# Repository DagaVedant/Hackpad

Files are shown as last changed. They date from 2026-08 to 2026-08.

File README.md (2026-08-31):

# minipad

a 3x3 macropad for shortcuts, built for [hackpad](https://hackpad.hackclub.com).
9 keys, a rotary encoder, per key rgb, and a 0.91" oled that shows a clock and a
spinning globe.

## the pad

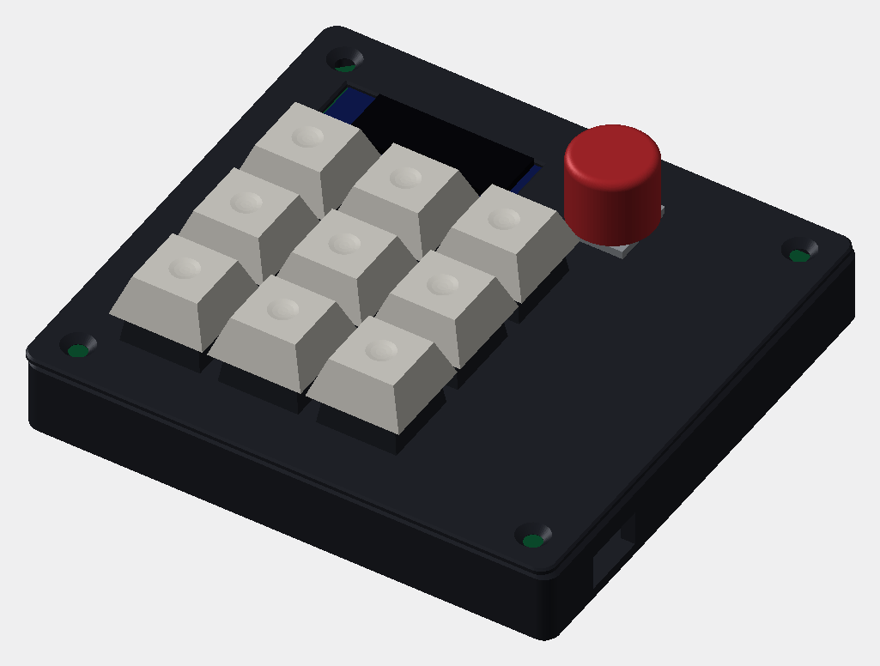
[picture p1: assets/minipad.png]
minipad


rendered from the actual case and board files in this repo, not a mockup. photo
of the real thing goes here once it's printed and soldered.

## schematic

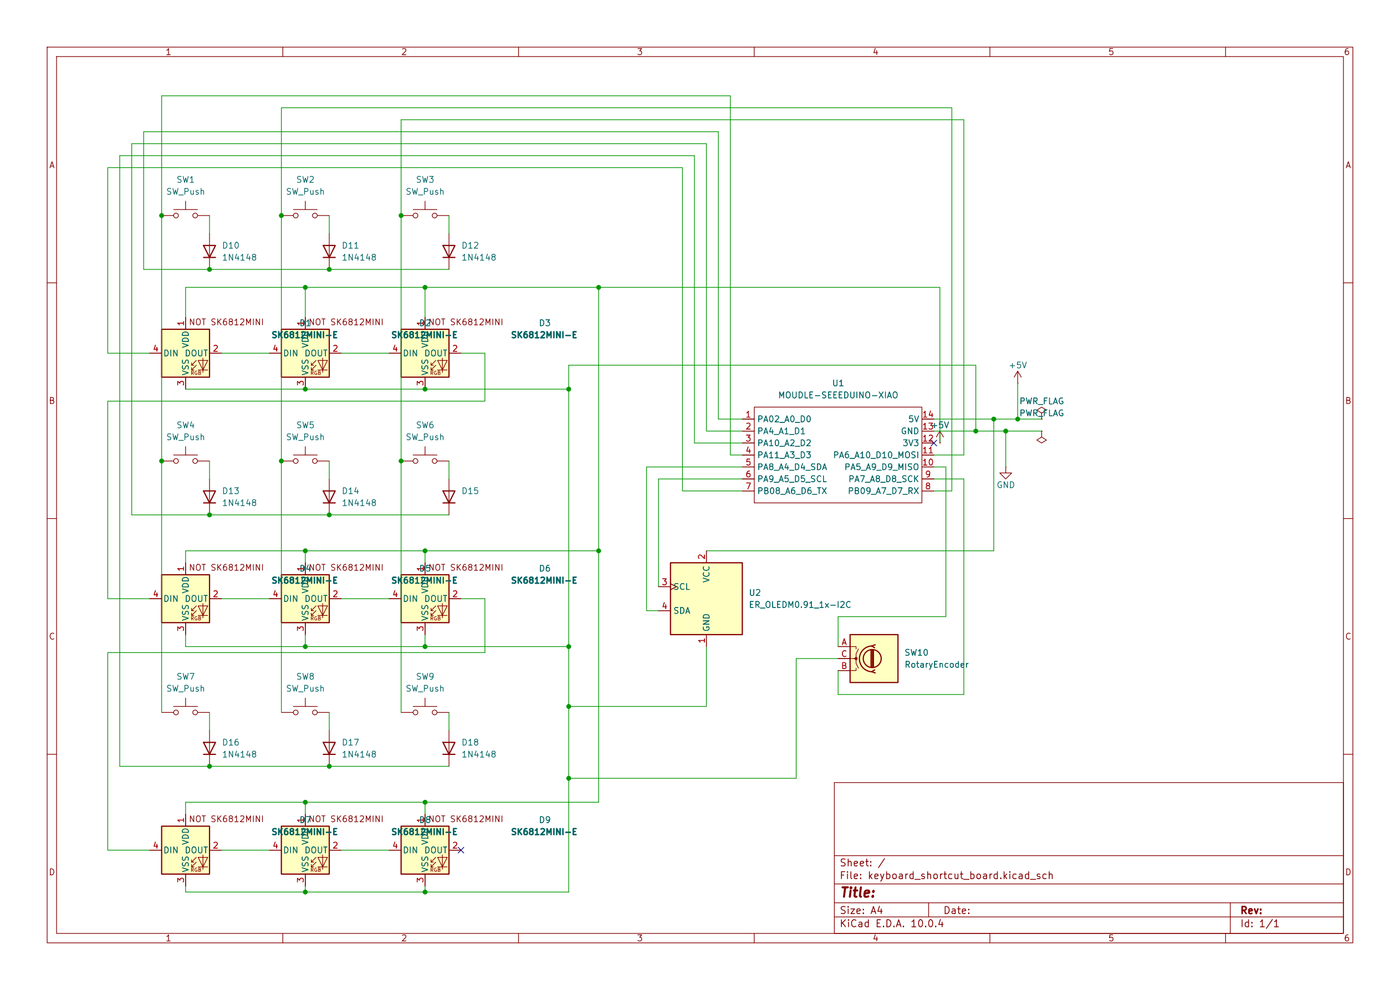
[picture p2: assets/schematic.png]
schematic


## pcb

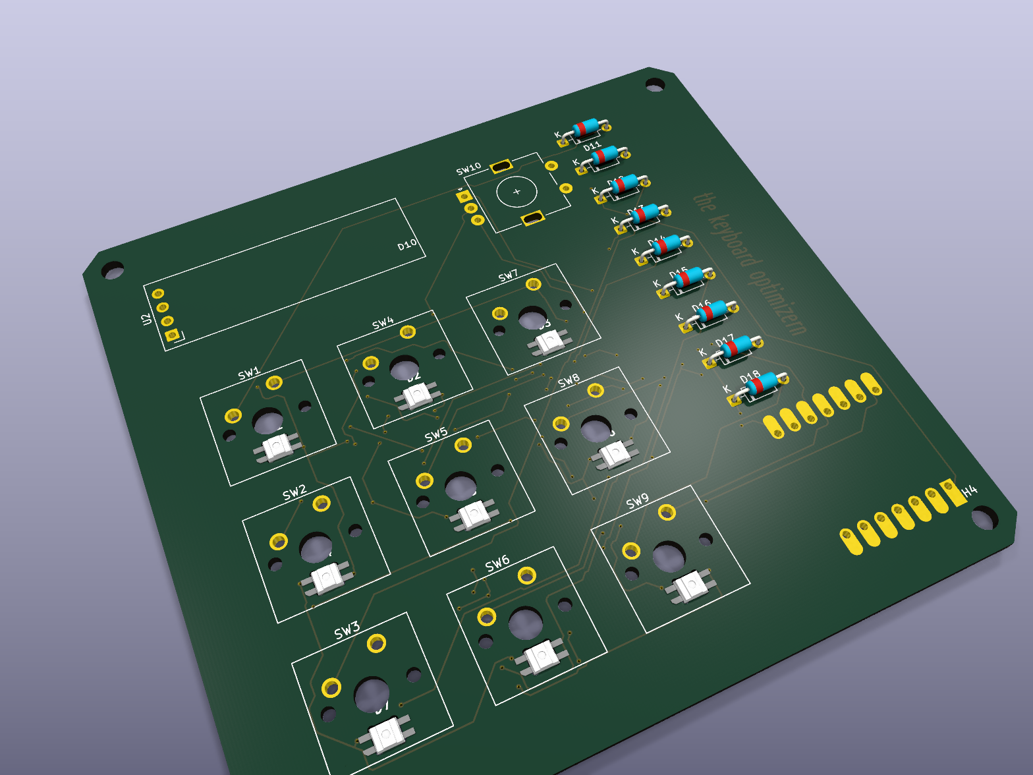
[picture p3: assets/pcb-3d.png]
pcb


96.38 x 90.90mm, 2 layers. chamfered corners, and 4x m3 mounting holes on an
88.226 x 82.748mm rectangle for a sandwich case.

the 9 sk6812mini-e leds are reverse mounted. they sit in milled slots in the
board and shine up through the switches, so the lighting is per key rather than
underglow.

## case

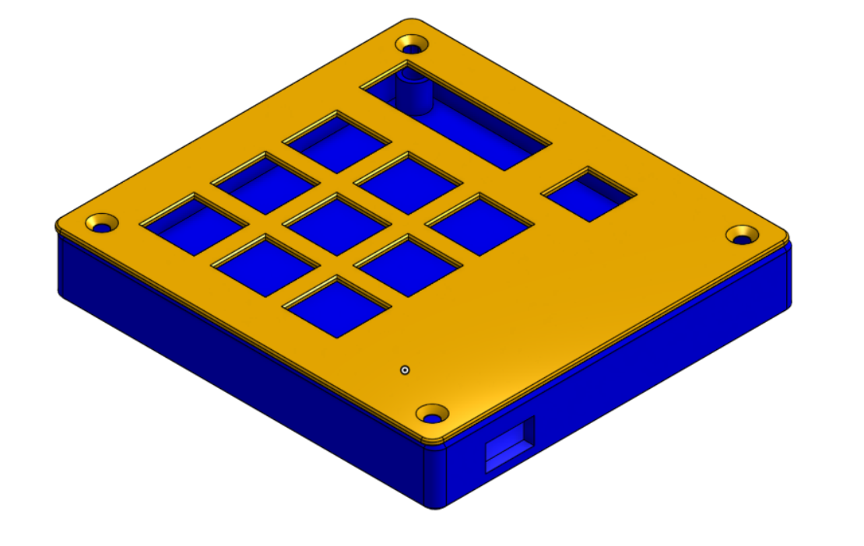
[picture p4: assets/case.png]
case


[open the assembly in onshape](https://cad.onshape.com/documents/58a01ca66c97d1b4010a7a00/w/fc5b38729478e50a03cca7d8/e/0de70a1a8ca9505f551d6dfe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)

a sandwich: 1.5mm switch plate on top, the pcb in the middle, tray bottom
underneath. 102.38 x 96.90mm overall, 16.6mm tall closed.

the pcb rests on four bosses at 10mm, which leaves a 7.5mm cavity under the
board for the reverse mounted leds and the xiao. m3 heatset inserts drop into
the bosses from above, and four m3 screws through the plate into those inserts
hold the stack together. the only overhang is the usb-c slot in the side wall,
which is a 7mm bridge.

`production/Top.STEP` and `production/Bottom.STEP` are the two printable parts.
`cad/Assembly.STEP` is the whole thing put together, with the pcb in it.

## oled

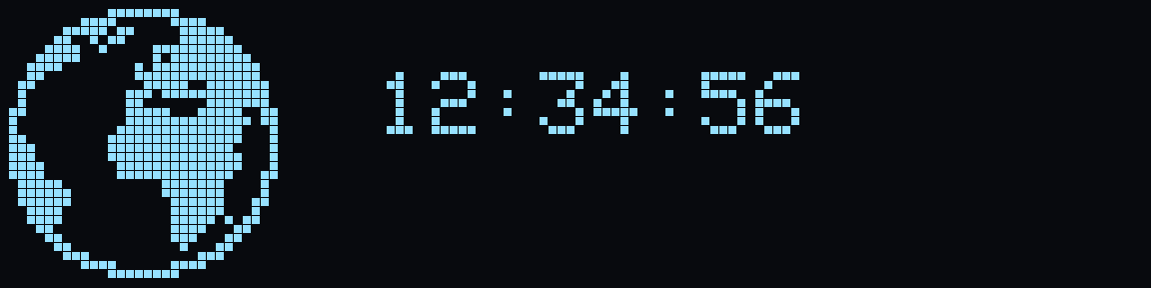
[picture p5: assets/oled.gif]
oled


the globe is generated from real natural earth coastline data. 24 frames, made
by projecting the land polygons onto a tilted sphere, so those are actual
continents at 32x32 pixels.

## bom

| qty | part | refs | in the hackpad kit? |
|---|---|---|---|
| 1 | seeed xiao rp2040 | U1 | yes (1 supplied) |
| 9 | mx style switch | SW1-SW9 | yes (16 supplied) |
| 9 | 1n4148 diode, do-35 | D10-D18 | yes (20 supplied) |
| 9 | sk6812mini-e rgb led | D1-D9 | yes (20 supplied) |
| 1 | ec11 rotary encoder, 20mm d-shaft | SW10 | yes (2 supplied) |
| 1 | 0.91" 128x32 i2c oled | U2 | yes (1 supplied) |
| 9 | dsa blank keycap | - | yes (16 supplied) |
| 4 | m3x16 screw | H1-H4 | yes (6 supplied) |
| 4 | m3x5x4 heatset insert | H1-H4 | yes (6 supplied) |
| 1 | knob for the encoder | - | **no, print it or source it yourself** |

everything except the encoder knob comes from the standard kit.

## keymap

| | | |
|---|---|---|
| open spotify | open chrome | open vs code |
| f11 | screenshot | calculator |
| copy | paste | undo |

the encoder does volume.

the three app launchers use windows taskbar shortcuts (`win`+`1`/`2`/`3`), so
**pin spotify, chrome and vs code to the first three taskbar slots** and the top
row works with no extra software.

## clock

there's no rtc on the board and usb hid can't send the time, so the clock
free runs from a timer and you set it by hand:

- hold the two **top corner keys** together to toggle set mode
- **encoder** adjusts minutes
- **top left / top right** keys adjust hours
- **top middle** exits

it resets to 00:00:00 whenever you unplug it, and drifts a few seconds a day.

## pins

| xiao pin | rp2040 | function |
|---|---|---|
| d0, d1, d2 | gp26, gp27, gp28 | matrix columns |
| d3, d7, d10 | gp29, gp1, gp3 | matrix rows |
| d4, d5 | gp6, gp7 | oled i2c (sda, scl) |
| d6 | gp0 | sk6812 data |
| d8, d9 | gp2, gp4 | encoder b, a |

3x3 matrix, `row2col`. all 11 gpio are used, which is why the encoder's push
switch isn't wired.

## firmware

qmk. `production/firmware.uf2` is prebuilt, so to flash it just double tap reset
on the xiao and drag the file onto the drive that appears.

to build it yourself, drop `firmware/` into
`qmk_firmware/keyboards/minipad/` and run:

```
qmk compile -kb minipad -km default
```

## layout

```
pcb/         kicad source and the board step
firmware/    qmk source
cad/         assembled case model
production/  everything you need to build one: gerbers, the two
             printable case parts, and the prebuilt uf2
assets/      images for this readme
```

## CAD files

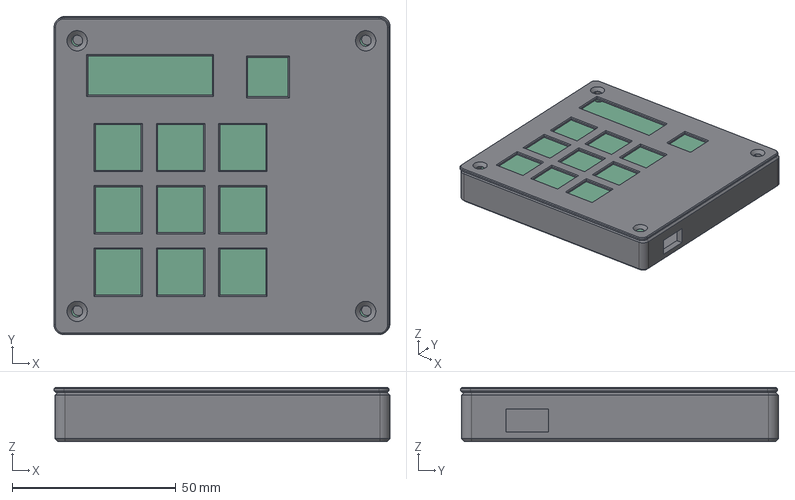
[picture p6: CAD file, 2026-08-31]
cad/Assembly.STEP
102.7 x 97.3 x 16.6 mm
case_bottom
pcb
switch_plate

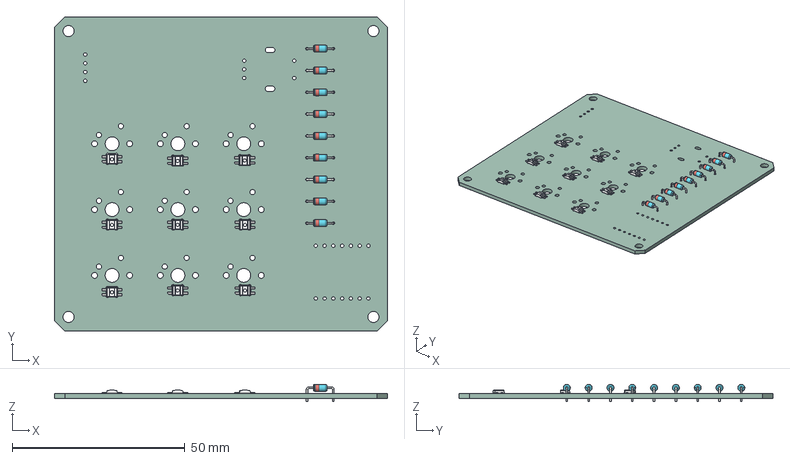
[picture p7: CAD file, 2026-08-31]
pcb/minipad.step
96.4 x 90.9 x 5.01 mm
Pin1 x 9
Pin2 x 9
Pin3 x 9
Pin4 x 9
D_DO-35_SOD27_P7.62mm_Horizontal x 9
minipad_PCB

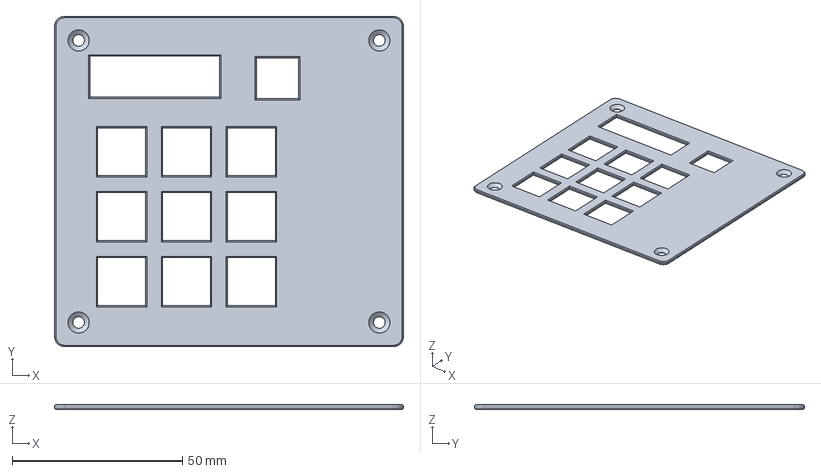
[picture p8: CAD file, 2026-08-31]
production/Top.STEP
102.4 x 96.9 x 1.50 mm

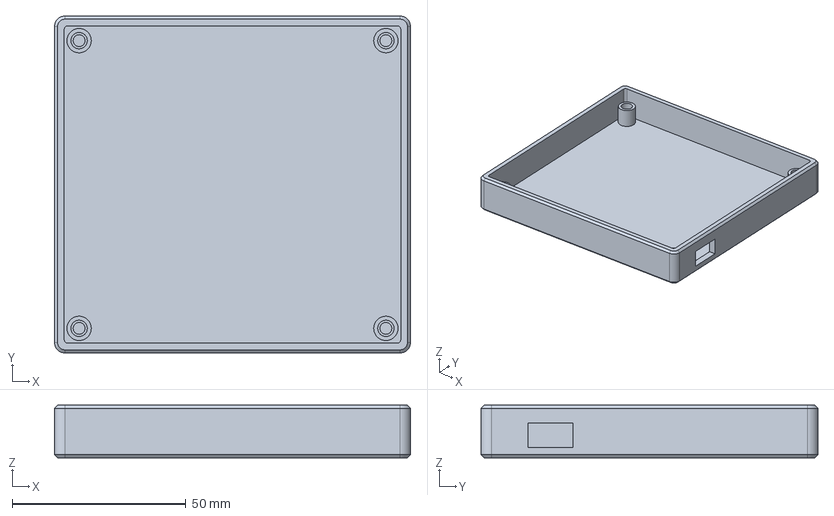
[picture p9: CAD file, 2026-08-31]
production/Bottom.STEP
102.4 x 96.9 x 15.1 mm

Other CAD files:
pcb/keyboard_shortcut_board.step

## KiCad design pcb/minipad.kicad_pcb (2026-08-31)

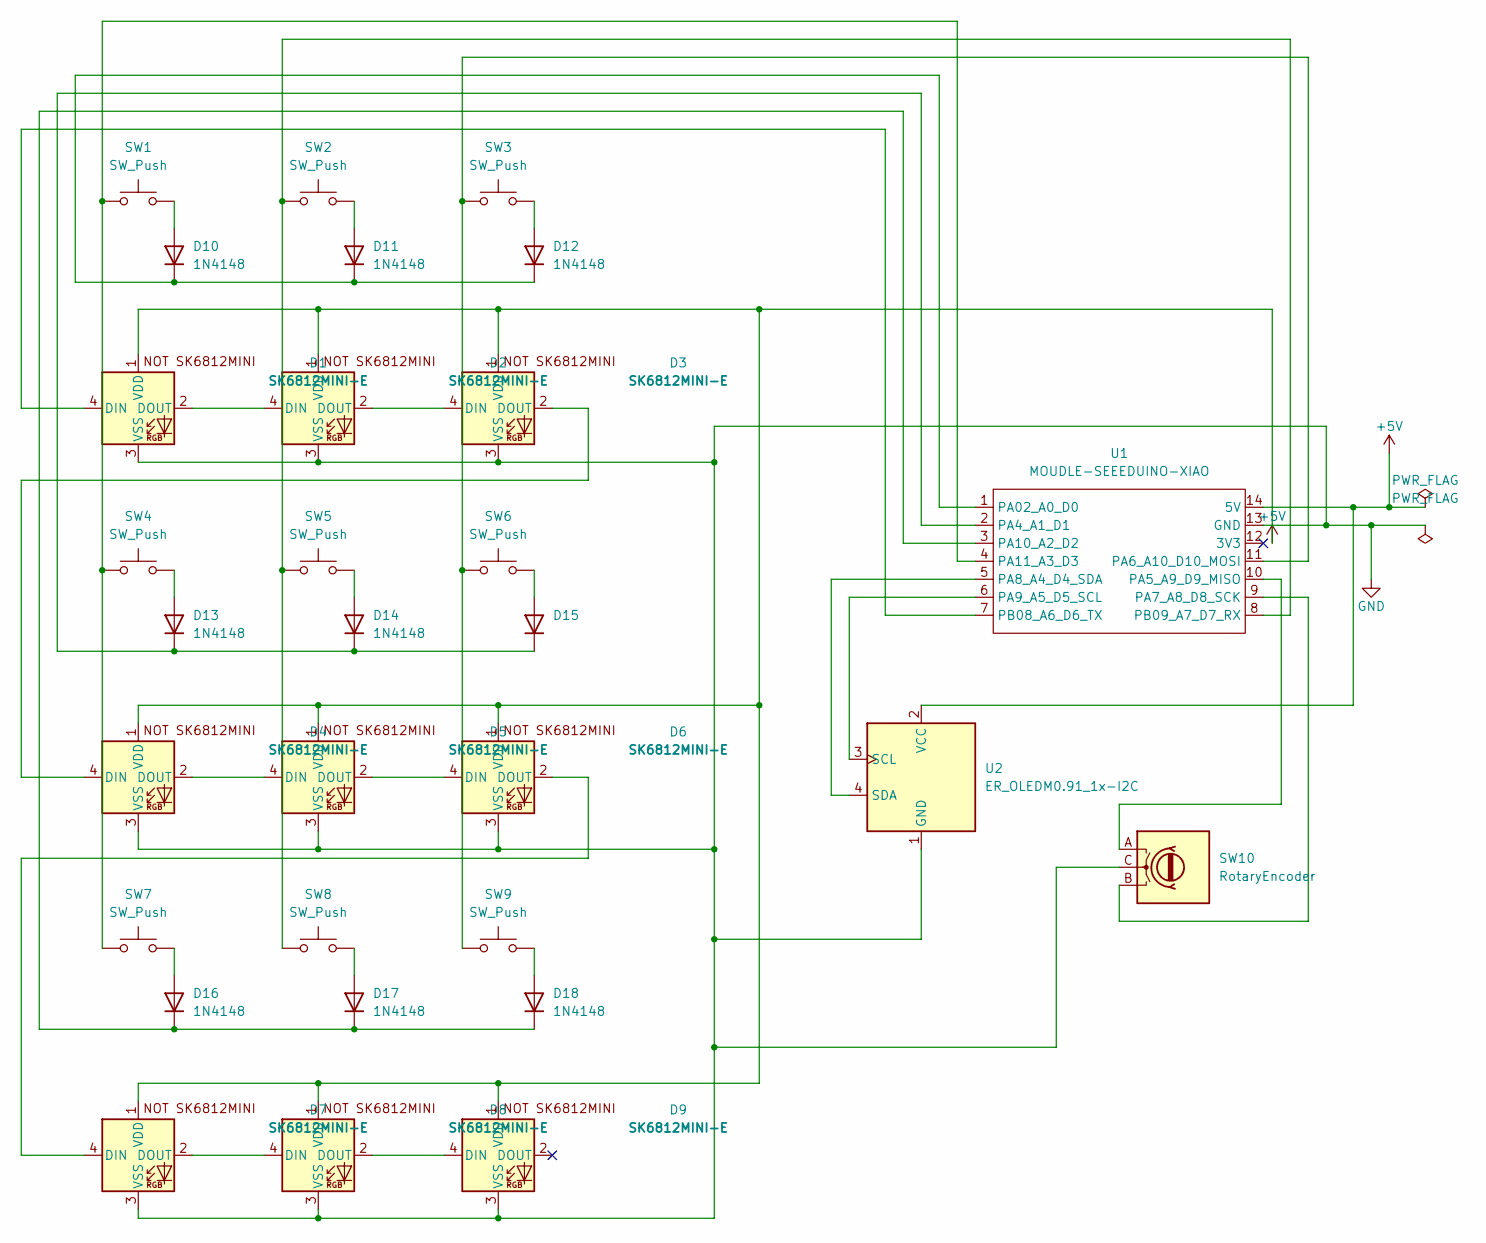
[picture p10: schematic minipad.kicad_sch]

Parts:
D1, D2, D3, D4, D5, D6, D7, D8, D9: SK6812MINI-E; SK6812MINI-E_fixed
D10, D11, D12, D13, D14, D15, D16, D17, D18: 1N4148; D_DO-35_SOD27_P7.62mm_Horizontal
SW1, SW2, SW3, SW4, SW5, SW6, SW7, SW8, SW9: SW_Push; SW_Cherry_MX_1.00u_PCB
SW10: RotaryEncoder; RotaryEncoder_Alps_EC11E-Switch_Vertical_H20mm
U1: MOUDLE-SEEEDUINO-XIAO; XIAO-Generic-Hybrid-14P-2.54-21X17.8MM
U2: ER_OLEDM0.91_1x-I2C

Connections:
+5V: D1.1 (VDD), D2.1 (VDD), D3.1 (VDD), D4.1 (VDD), D5.1 (VDD), D6.1 (VDD), D7.1 (VDD), D8.1 (VDD), D9.1 (VDD), U1.14 (5V), U2.2 (VCC)
GND: D1.3 (VSS), D2.3 (VSS), D3.3 (VSS), D4.3 (VSS), D5.3 (VSS), D6.3 (VSS), D7.3 (VSS), D8.3 (VSS), D9.3 (VSS), SW10.C, U1.13 (GND), U2.1 (GND)
unnamed: D1.4 (DIN), U1.7 (PB08_A6_D6_TX)
unnamed: D1.2 (DOUT), D2.4 (DIN)
unnamed: D2.2 (DOUT), D3.4 (DIN)
unnamed: D3.2 (DOUT), D4.4 (DIN)
unnamed: D4.2 (DOUT), D5.4 (DIN)
unnamed: D5.2 (DOUT), D6.4 (DIN)
unnamed: D6.2 (DOUT), D7.4 (DIN)
unnamed: D7.2 (DOUT), D8.4 (DIN)
unnamed: D8.2 (DOUT), D9.4 (DIN)
unnamed: D10.2 (A), SW1.2
unnamed: D10.1 (K), D11.1 (K), D12.1 (K), U1.1 (PA02_A0_D0)
unnamed: D11.2 (A), SW2.2
unnamed: D12.2 (A), SW3.2
unnamed: D13.2 (A), SW4.2
unnamed: D13.1 (K), D14.1 (K), D15.1 (K), U1.2 (PA4_A1_D1)
unnamed: D14.2 (A), SW5.2
unnamed: D15.2 (A), SW6.2
unnamed: D16.2 (A), SW7.2
unnamed: D16.1 (K), D17.1 (K), D18.1 (K), U1.3 (PA10_A2_D2)
unnamed: D17.2 (A), SW8.2
unnamed: D18.2 (A), SW9.2
unnamed: SW10.A, U1.10 (PA5_A9_D9_MISO)
unnamed: SW3.1, SW6.1, SW9.1, U1.11 (PA6_A10_D10_MOSI)
unnamed: SW10.B, U1.9 (PA7_A8_D8_SCK)
unnamed: U1.5 (PA8_A4_D4_SDA), U2.4 (SDA)
unnamed: U1.6 (PA9_A5_D5_SCL), U2.3 (SCL)
unnamed: SW1.1, SW4.1, SW7.1, U1.4 (PA11_A3_D3)
unnamed: SW2.1, SW5.1, SW8.1, U1.8 (PB09_A7_D7_RX)

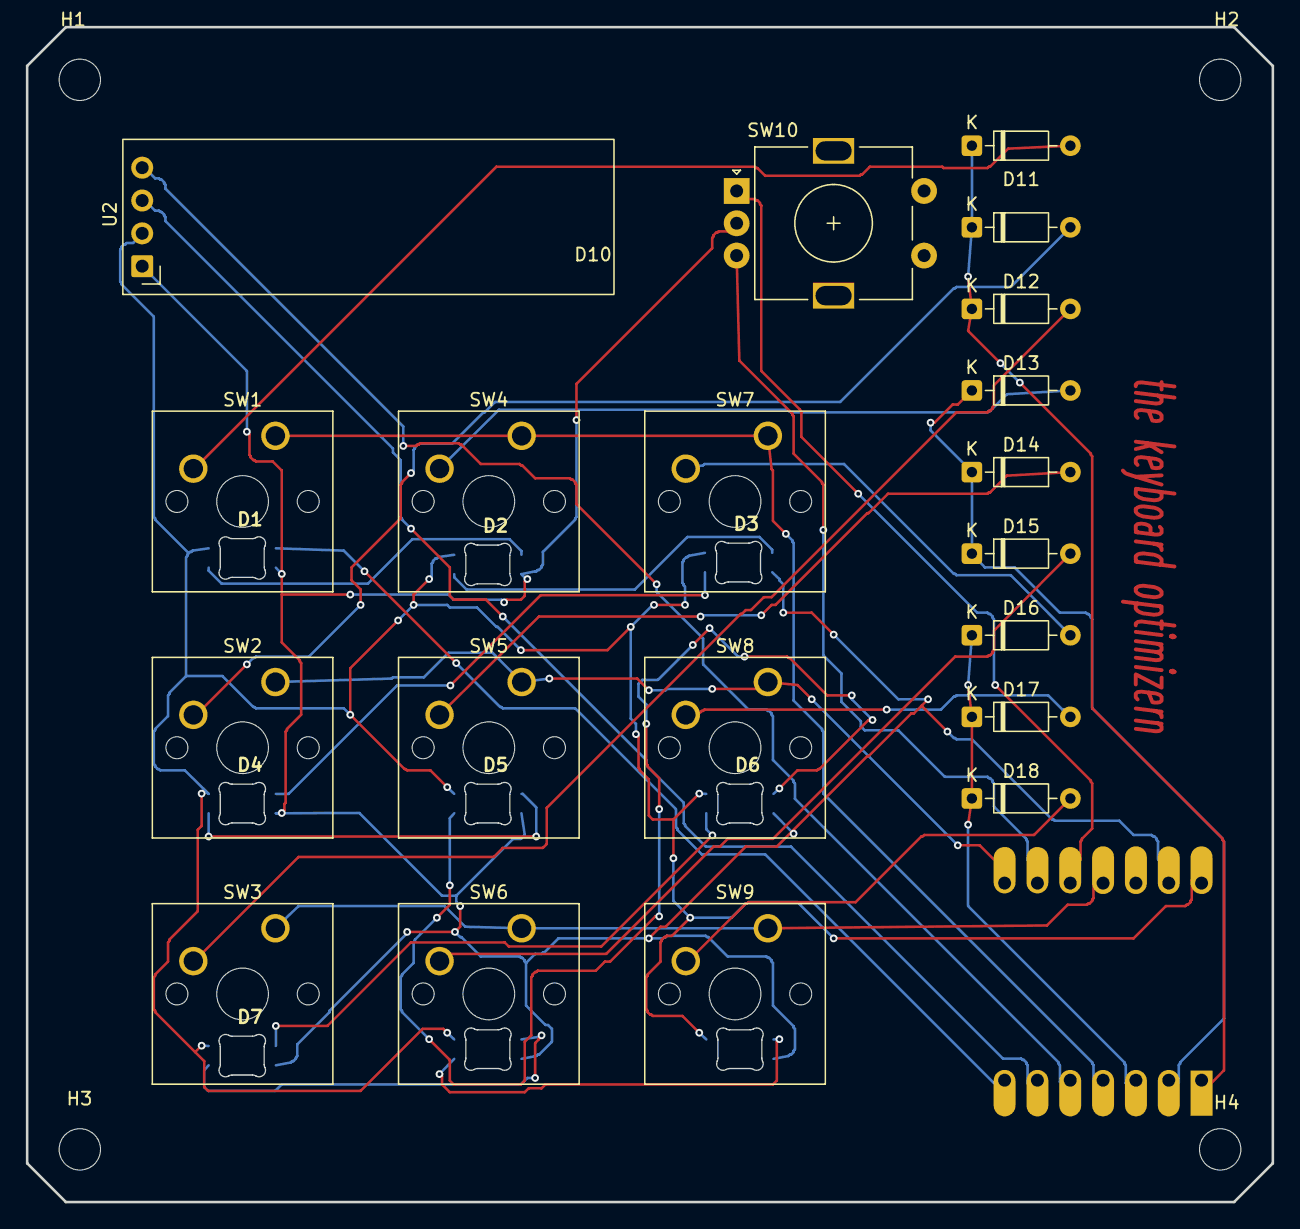
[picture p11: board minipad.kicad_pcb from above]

Board: 2 copper layers, 96.4 x 90.9 mm, 34 parts (1 on the bottom side), 30 nets.

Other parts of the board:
H1, H2, H3, H4: MountingHole_3.2mm_M3

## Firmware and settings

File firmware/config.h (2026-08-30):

#define ENCODER_A_PINS { GP4 }
#define ENCODER_B_PINS { GP2 }

#define WS2812_DI_PIN GP0
#define RGBLIGHT_LED_COUNT 9
#define RGBLIGHT_LIMIT_VAL 120

#define I2C_DRIVER I2CD1
#define I2C1_SDA_PIN GP6
#define I2C1_SCL_PIN GP7

#define OLED_TIMEOUT 0

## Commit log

2026-08-30 just build the schematic and pcb
    [keyboard_shortcut_board.kicad_pcb, keyboard_shortcut_board.kicad_sch]
2026-08-30 fix schematic power rails
    [keyboard_shortcut_board.kicad_pcb, keyboard_shortcut_board.kicad_sch]
2026-08-30 move XIAO 5mm right so USB-C clears the case wall
    Receptacle sat 7.64mm inboard of the right board edge after the mounting
    margin was added, too deep for a USB-C plug overmold to reach. Now 2.64mm.
    Re-routed all 13 nets on the XIAO. Also repointed the SK6812 footprints at
    the 3D model that actually ships with KiCad. DRC unchanged: 0 unconnected,
    44 LED slot-clearance errors inherent to the supplied footprint.
    [keyboard_shortcut_board.kicad_pcb]
2026-08-30 square up the M3 mounting holes and add the board STEP
    Holes were off a symmetric pattern by up to 0.7mm, so the case could not use
    a rectangular pattern. Now a true 88.226 x 82.748 rectangle, 4.076mm inset on
    all four edges.
    That inset centres the bottom-right hole in the 8.15mm band between the XIAO
    and the board edge, raising its clearance from 3.55 to 4.08mm so the heatset
    boss can be 8.15mm OD instead of 7.1mm.
    DRC unchanged: 0 unconnected, 44 LED slot-clearance errors from the supplied
    SK6812 footprint. Gerbers and STEP regenerated and verified against the board.
    [keyboard_shortcut_board.kicad_pcb, keyboard_shortcut_board.step]
2026-08-30 chamfer the board corners
    3mm chamfers on all four corners. Capped at 3mm by the M3 holes: they sit
    4.076mm in from each edge, so a bigger cut would leave under 2mm of board
    around the screw. The reference designs get away with large chamfers because
    they have no corner mounting holes.
    Bounding box unchanged at 96.38 x 90.90mm, no copper in the removed corners,
    DRC unchanged. Gerbers and STEP regenerated.
    [keyboard_shortcut_board.kicad_pcb, keyboard_shortcut_board.step]
2026-08-30 add compiled firmware.uf2
    Built with QMK 1.2.0 CLI, GNU Make 4.4.1 and Arm GNU Toolchain 12.2.
    text 33376 bytes, 131 UF2 blocks from 0x10000000, RP2040 family ID.
    Verified the keymap symbol and the encoder, OLED, RGB and I2C code are
    all linked in.
2026-08-30 OLED clock with spinning globe
    12-frame wireframe globe, 32x32, 1536 bytes of bitmap, rendered as a tilted
    sphere so the parallels project as ellipses and the rotation reads.
    No RTC exists in this QMK version and USB HID cannot deliver the time, so the
    clock free-runs from timer_read32 with an offset set by hand. Hold the two top
    corner keys to toggle a set layer, then the encoder adjusts minutes and the
    top-left and top-right keys adjust hours. All nine base functions survive.
    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
2026-08-30 replace the wireframe globe with a rendered Earth
    Frames are now rasterised from Natural Earth ne_110m_land coastline polygons:
    land polygons drawn into a 1440x720 equirectangular mask, then inverse
    orthographic projection per pixel at 4x supersampling with a 20 degree tilt.
    Real continents rather than a lat/lon grid.
    24 frames, 3072 bytes. text 38644 -> 40180.
2026-08-31 hackpad case v1
    [Hackpad Bottom.step, Hackpad Bottom.stl, Hackpad Top Cutout.step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]
2026-08-31 added even more features to the case
    [Hackpad Bottom v2.step, Hackpad Bottom.step, Hackpad Bottom.stl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]
2026-08-31 add case render to the readme
2026-08-31 add onshape case assembly
    [Hackpad Assembly v2.step]
2026-08-31 Update README.md to remove PCB routing details
    Removed images and descriptions related to PCB routing.
2026-08-31 fix plate seating in the case assembly
    [Hackpad Assembly v2.step]
2026-08-31 Rename project from 'keyboard shortcut board' to 'hackpad'
2026-08-31 rename case parts to Top/Bottom.STEP and add the full assembly
    [Assembly.STEP, Bottom.STEP, Top.STEP]
2026-08-31 move build outputs into production/
    [Bottom.STEP, Hackpad Assembly v2.step, Top.STEP]
2026-08-31 add overall pad shot and case fit view to the readme
2026-08-31 remove unused pcb-top asset
2026-08-31 remove the case fit render
2026-08-31 rename the project to minipad
    [minipad.kicad_pcb, minipad.kicad_sch, minipad.step]
